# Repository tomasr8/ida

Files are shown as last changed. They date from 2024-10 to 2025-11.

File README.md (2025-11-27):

# Ida - 3-key macropad

<p align="middle">
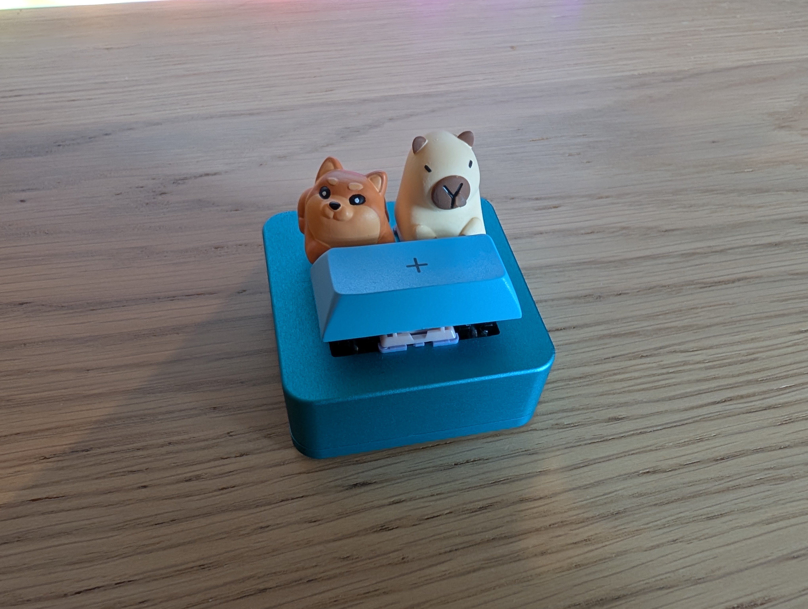
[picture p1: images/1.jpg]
  
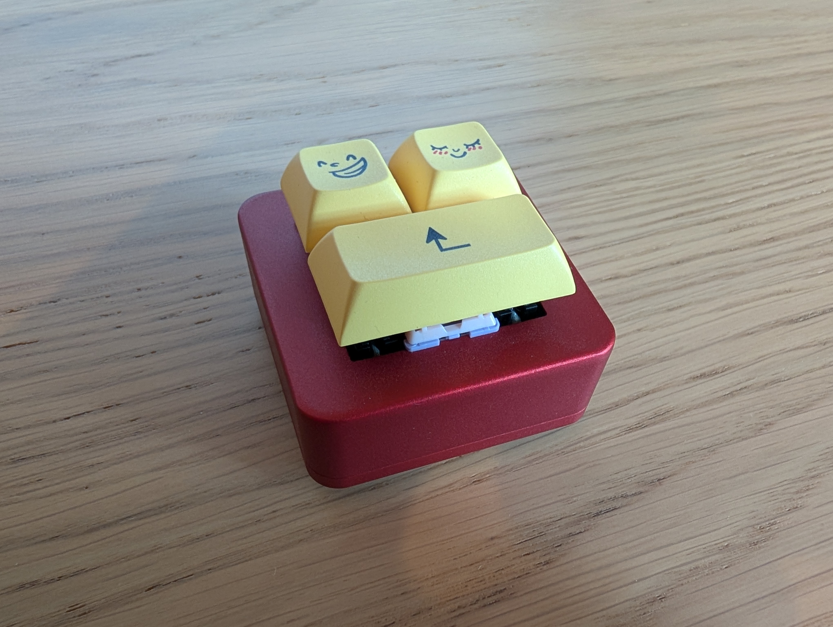
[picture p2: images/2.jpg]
  
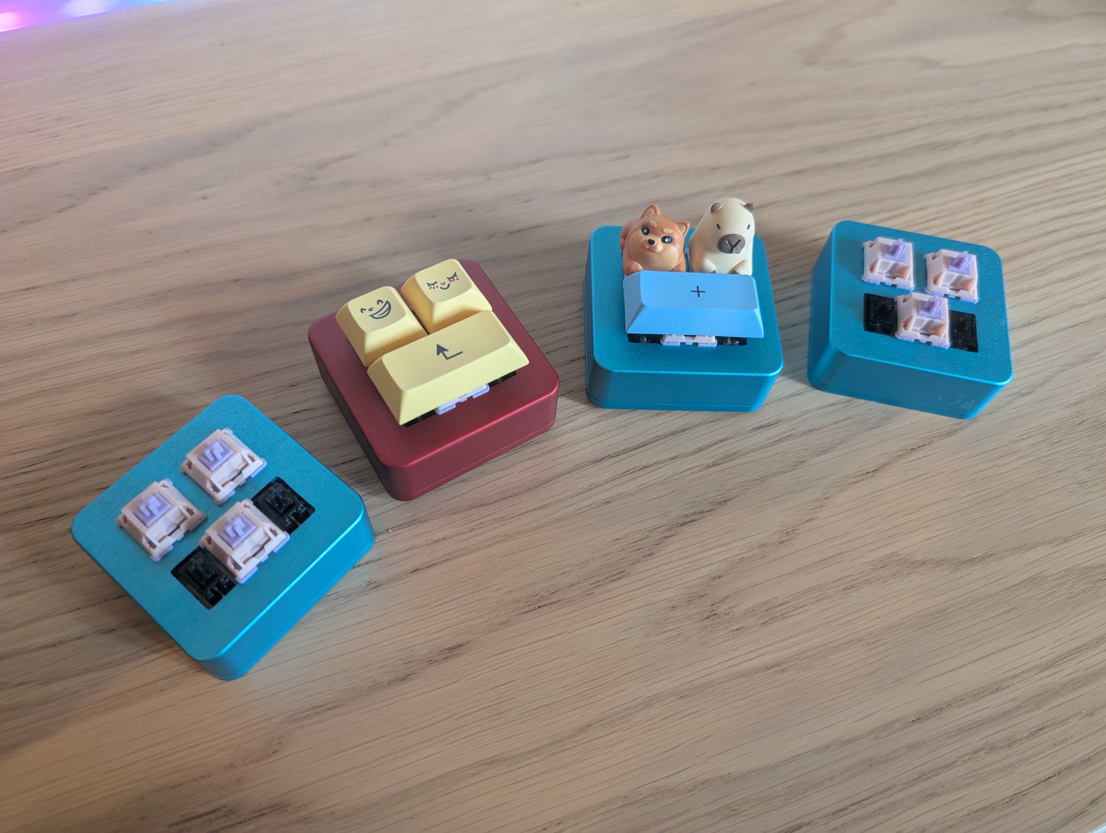
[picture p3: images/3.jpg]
  
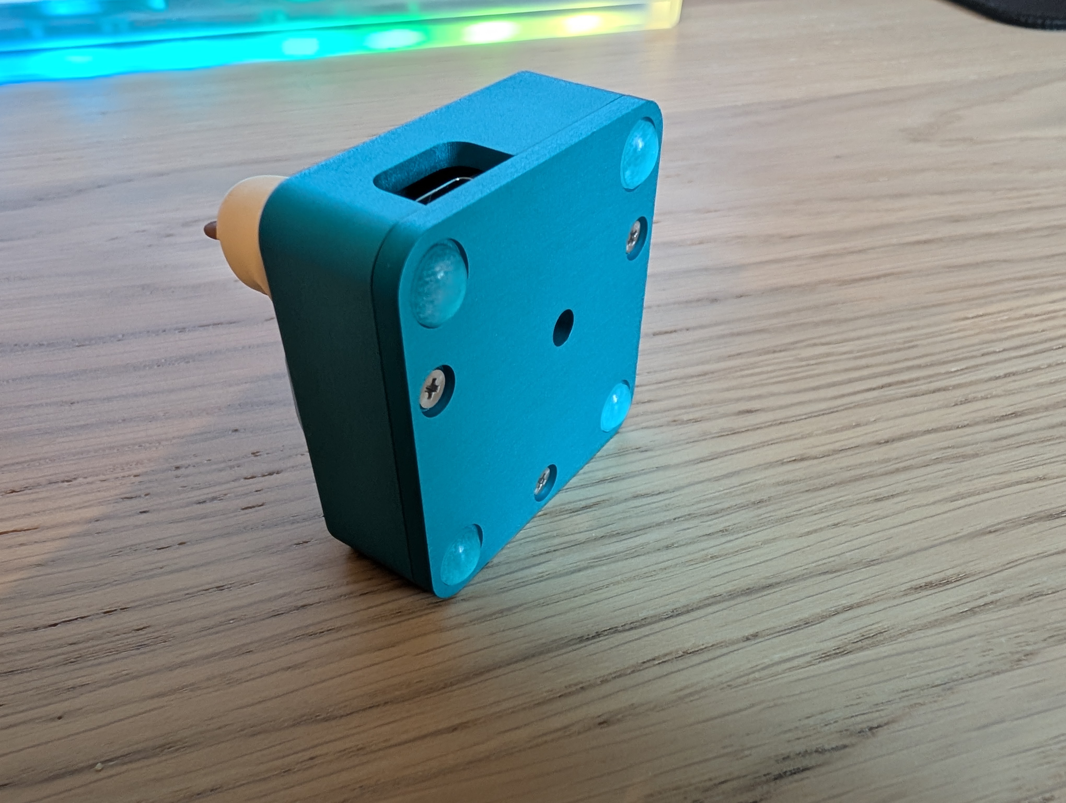
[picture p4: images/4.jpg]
  
</p>

# Table of Contents

- [Bill of Materials](#bill-of-materials)
- [Getting the parts made](#getting-the-parts-made)
- [Build guide](#build-guide)
- [Programming](#programming)
- [Schematics](#schematics)

# Bill of Materials

- **2x** 12x1 pin header
- **1x** Diode (_1N4148 DO-35_)
- **1x** Push button for resetting the board (_4x4x1.5mm_)
- **1x** Pro Micro or something with compatible pinout
- **3x** Keyboard switch
- **1x** 2u stabilizer
- **4x** 8mm rubber feet
- **3x** M2.5 screws
- Steady hands

# Getting the parts made

## PCB 

The gerbers are included in the repo in the [kicad](kicad/) directory. You can simply upload the gerbers to a service like JLCPCB.

Not that the entire Kicad project is included so you can also regenerate the gerbers with different settings if needed or adjust the PCB.

## Case

The case was CNC'd out of aluminium (again by JLCPCB). The case is made up of two ([top](top.stl), [bottom](bottom.stl)) parts.

The two parts are held together using 3 M2.5 screws. There is also a [drawing](drawing.pdf) showing the exact placement of the threads.

It might be possible to 3D print the case, but the screw threads might make it difficult.

# Build guide

**Step 1**: Solder the reset switch and the diode:

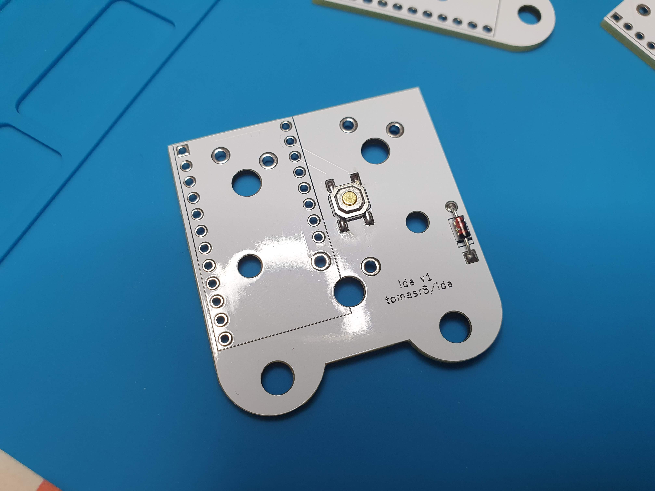
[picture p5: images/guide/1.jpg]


**Step 2**: Solder the pin headers:

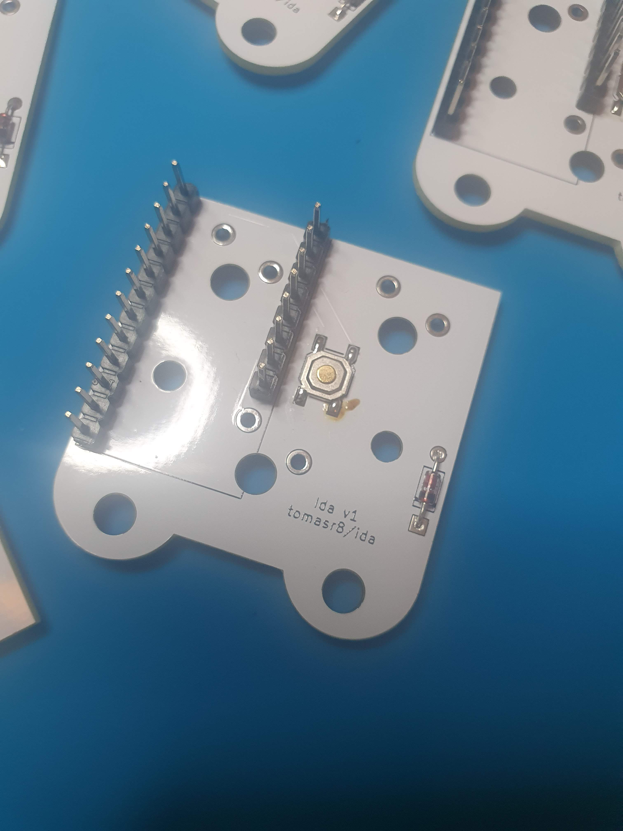
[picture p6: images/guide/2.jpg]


**Step 3**: Place the stabilizers:

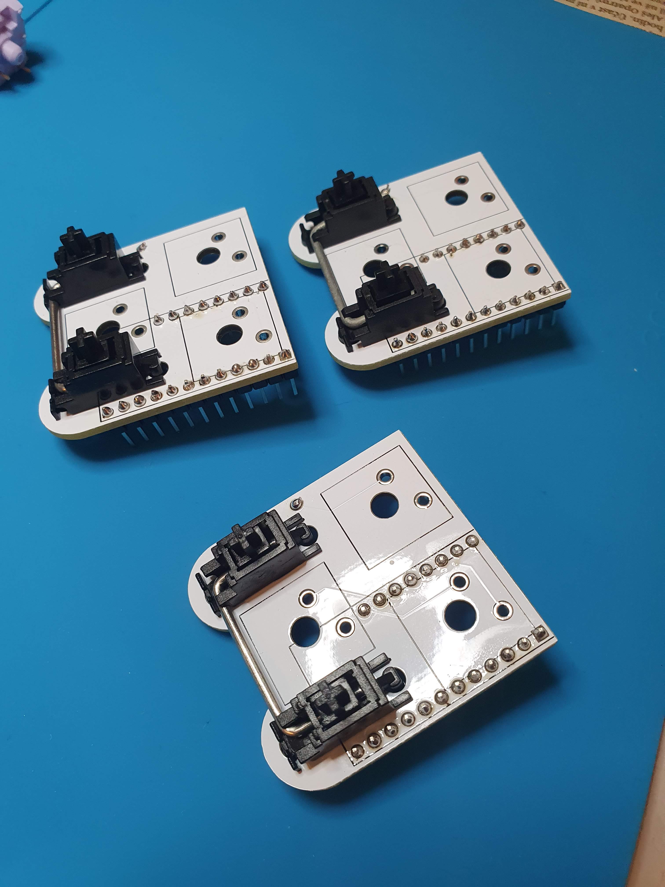
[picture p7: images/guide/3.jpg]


**Step 4**: Place switches in the enclosure:

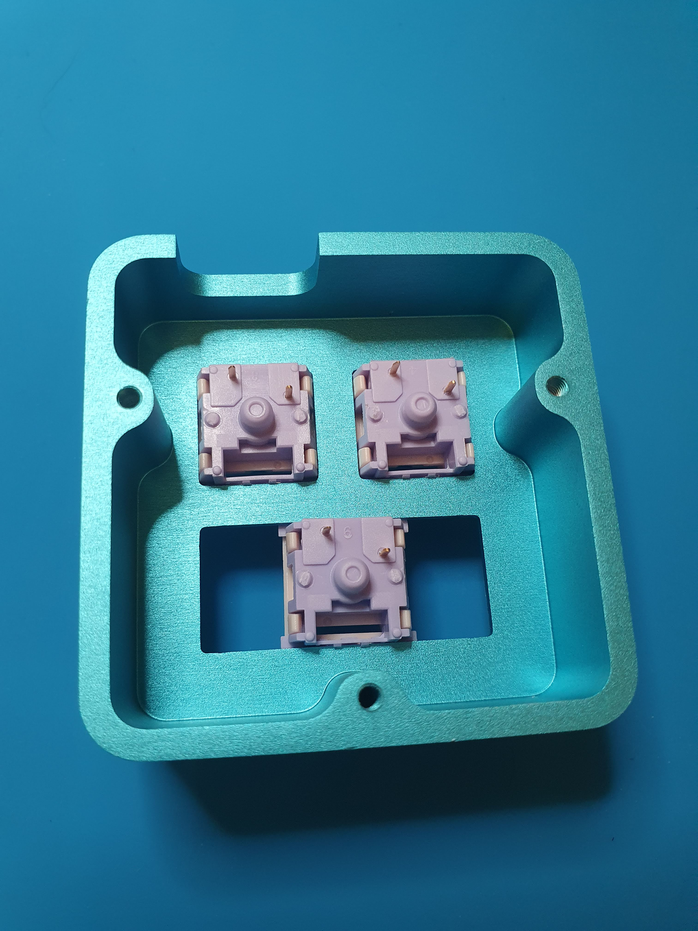
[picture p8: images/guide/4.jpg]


**Step 5**: Place the PCB inside the enclosure and solder the switches:

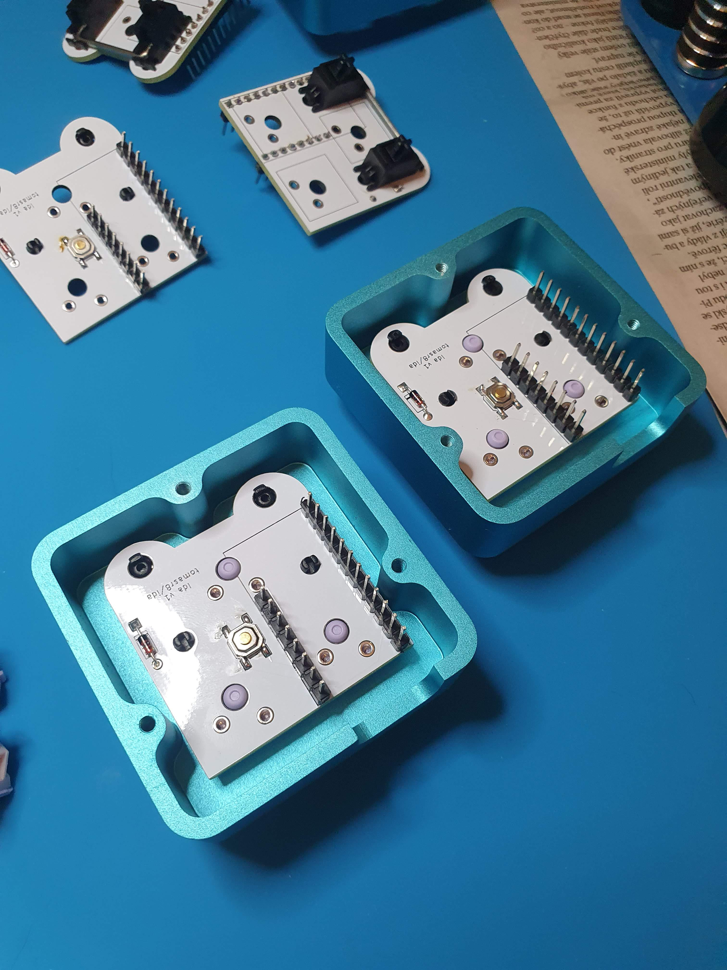
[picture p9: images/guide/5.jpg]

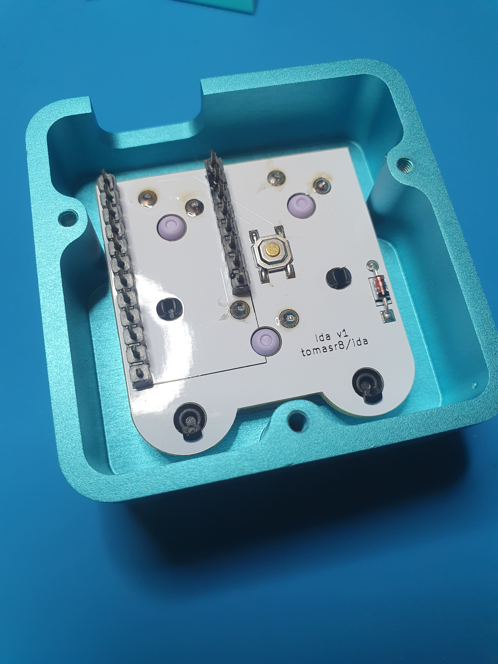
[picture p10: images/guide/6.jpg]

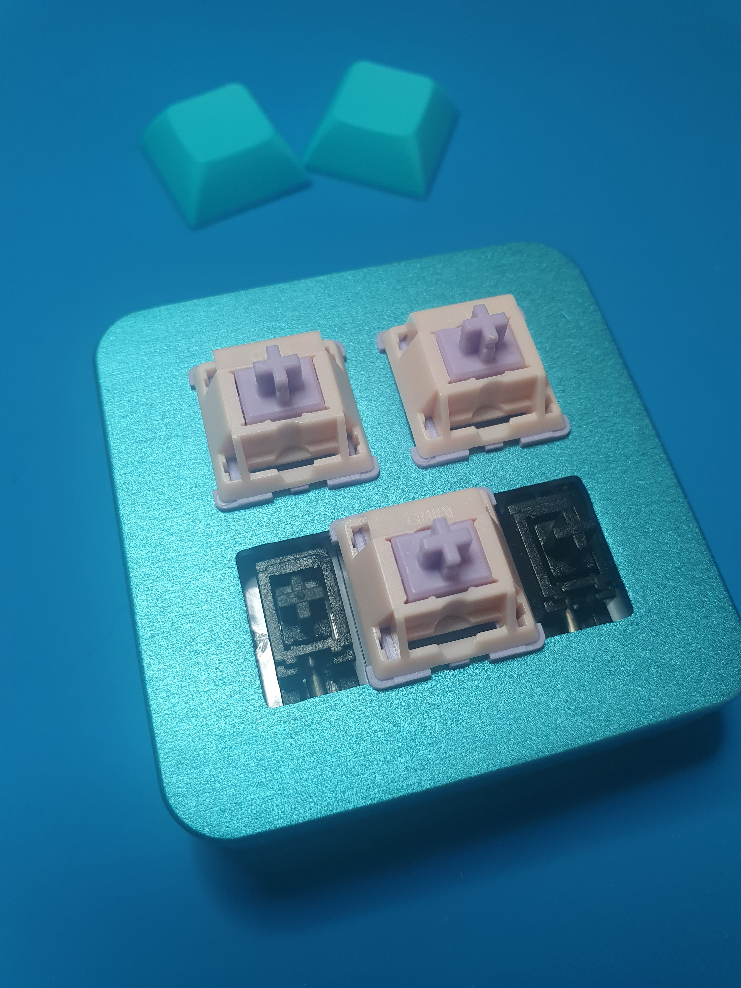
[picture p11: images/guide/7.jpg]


**Step 6**: Place and solder the Pro Micro:

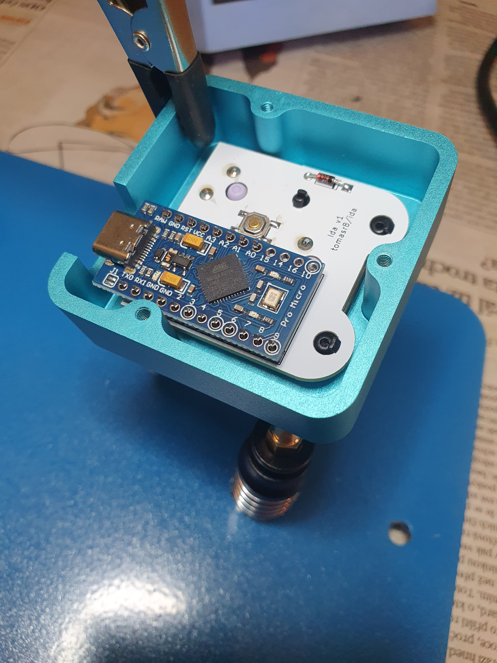
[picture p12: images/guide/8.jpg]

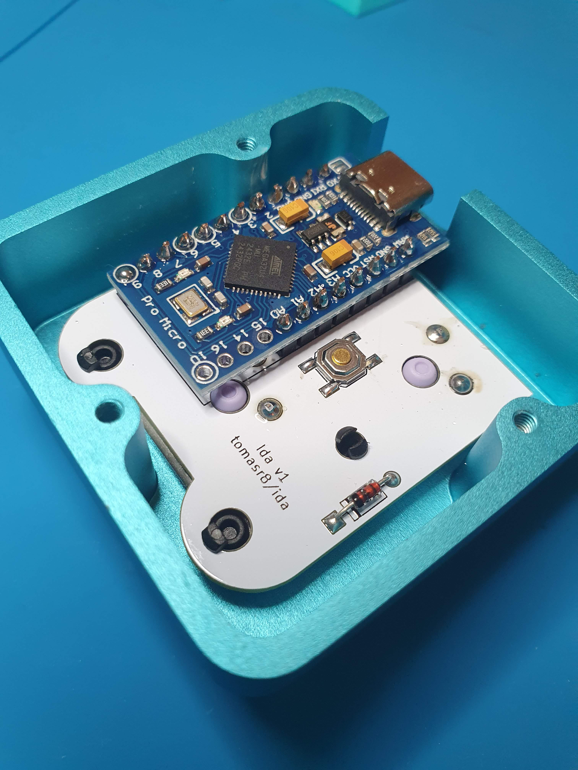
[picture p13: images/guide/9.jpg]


**Step 7**: Screw the bottom part of the case:

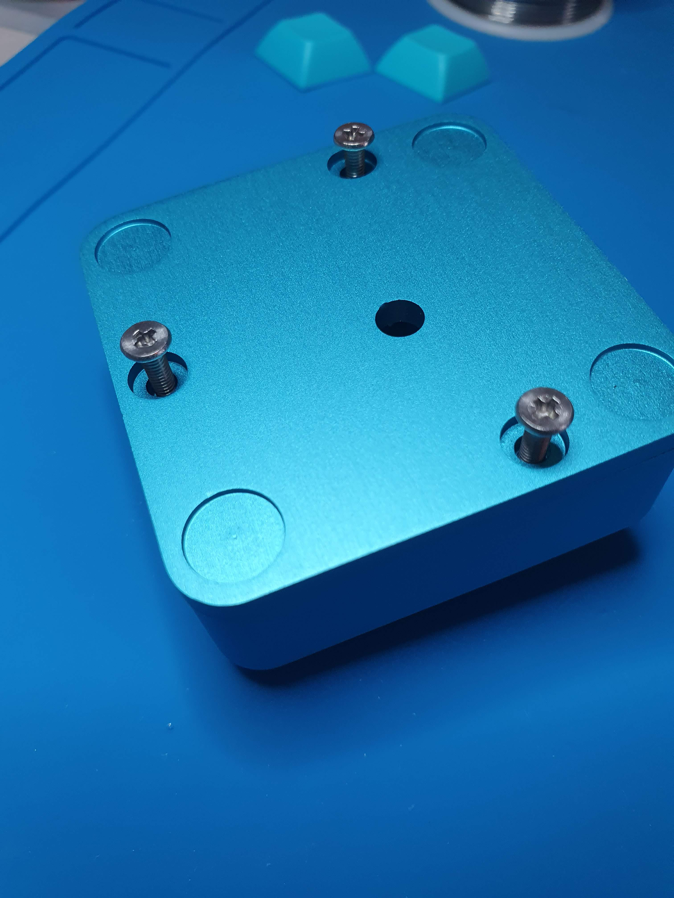
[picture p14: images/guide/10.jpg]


**Done!**



# Programming

I use QMK for programming the macropad. You can use my fork of QMK to change the keymap:
https://github.com/tomasr8/qmk_firmware/tree/ida/keyboards/ida

# Schematics

<p align="middle">
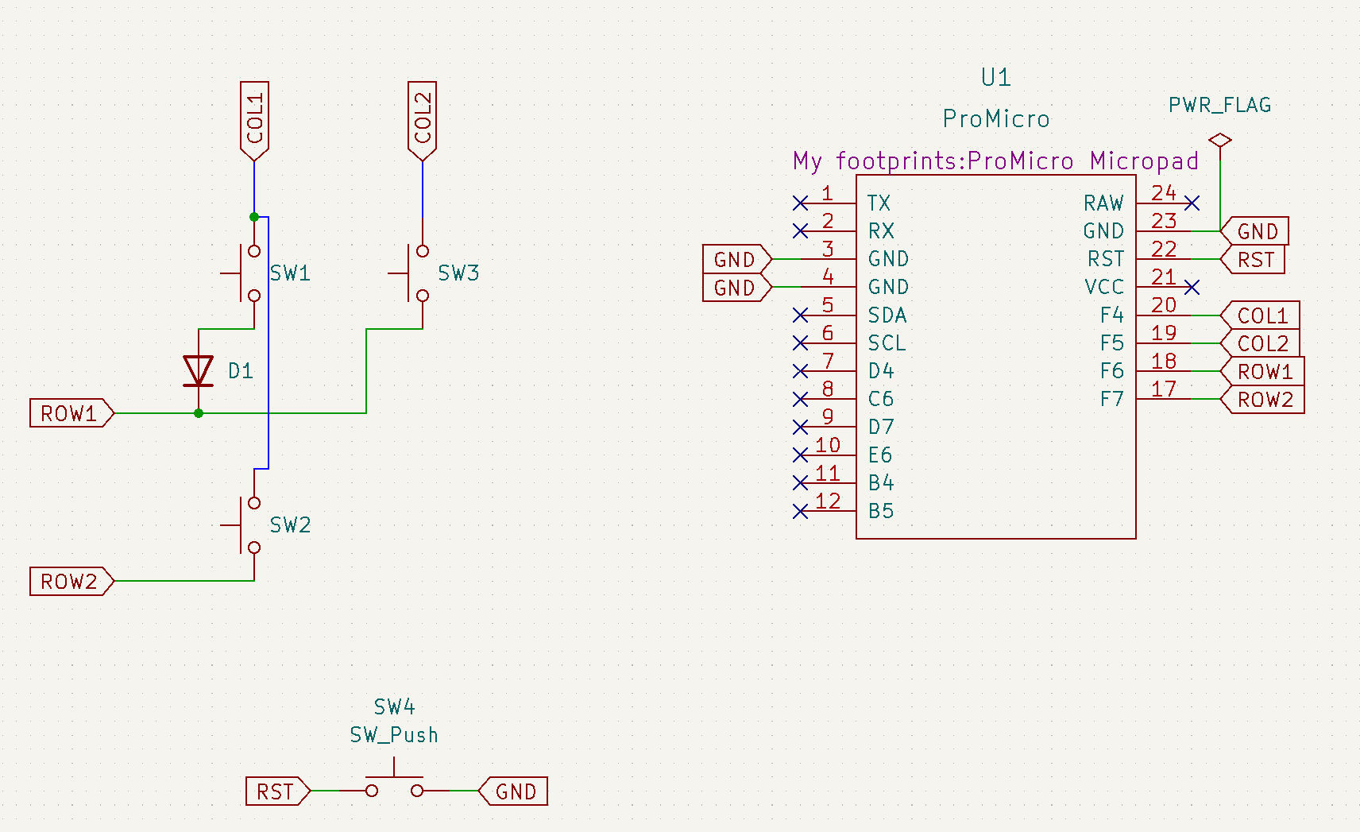
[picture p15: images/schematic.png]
  
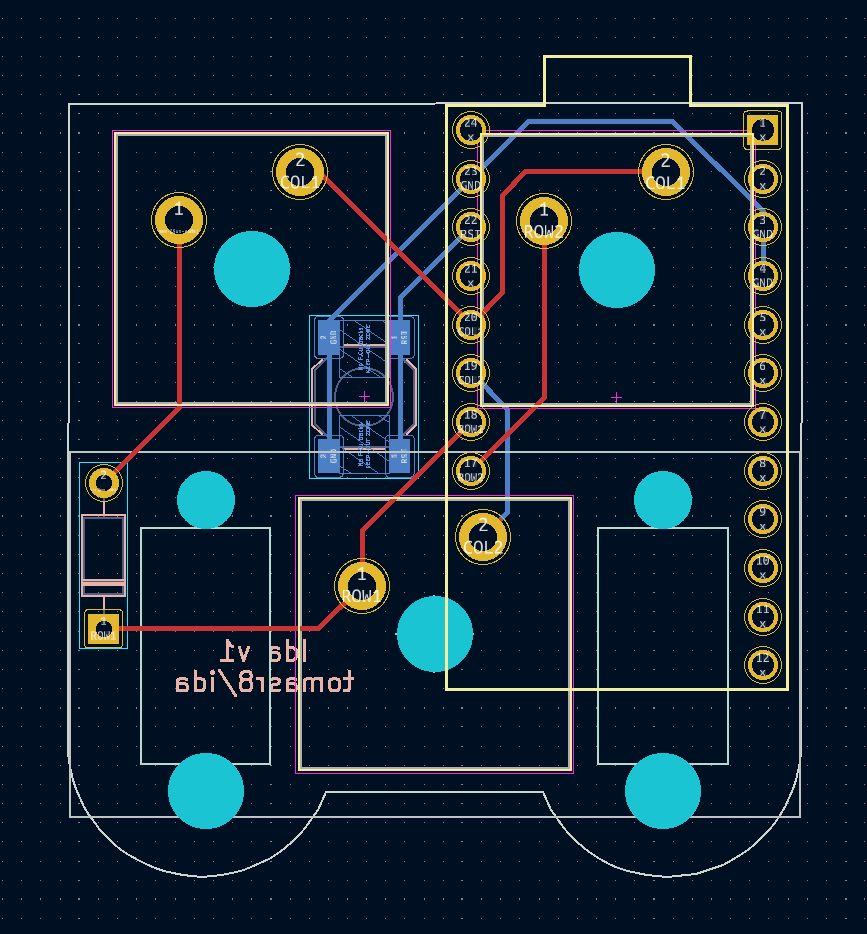
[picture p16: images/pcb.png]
  
</p>

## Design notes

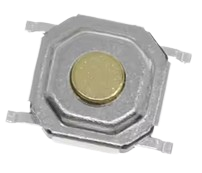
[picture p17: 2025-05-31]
images/pushbtn.png

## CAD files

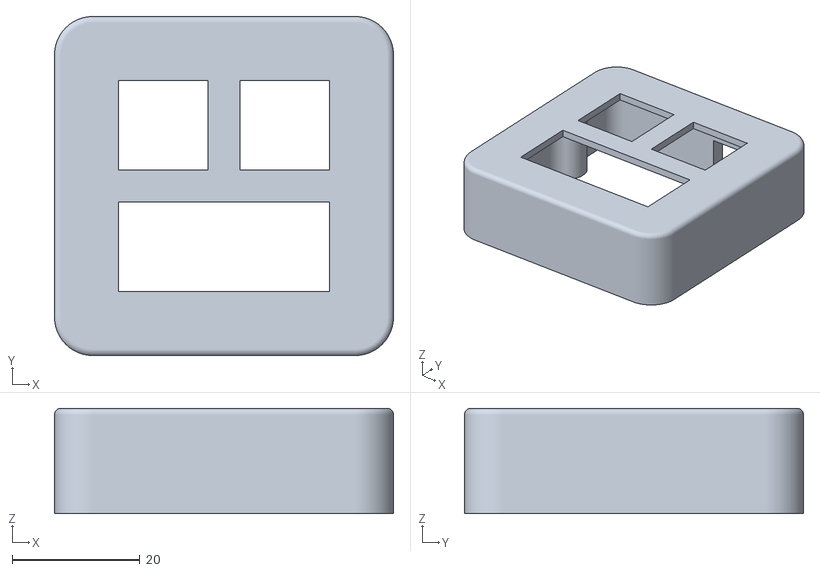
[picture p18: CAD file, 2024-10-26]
top.stl
53.0 x 53.0 x 16.5

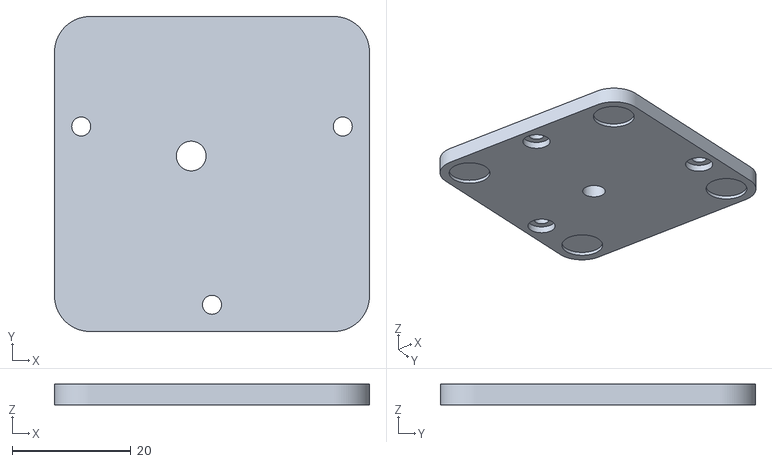
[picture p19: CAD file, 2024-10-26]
bottom.stl
53.0 x 53.0 x 3.50

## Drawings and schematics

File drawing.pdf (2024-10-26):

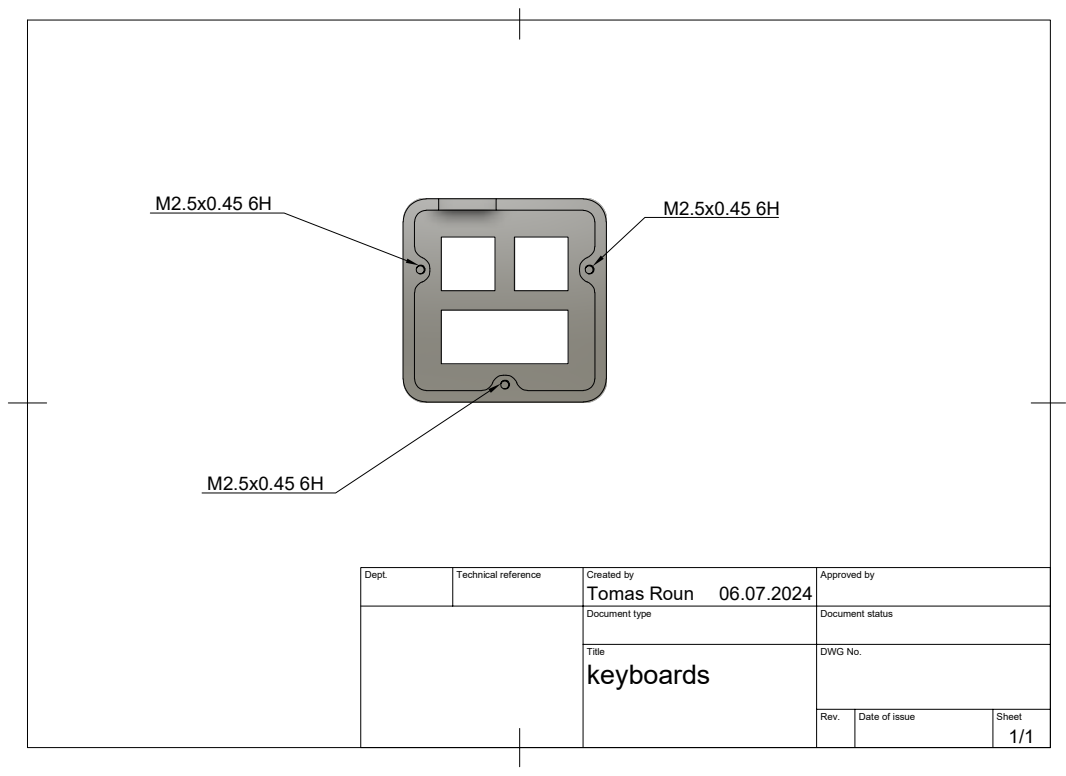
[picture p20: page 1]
Dept.; Technical reference; Created by; Approved by; Document type; Document status; Rev.; Date of issue; Sheet 06.07.2024; Tomas Roun

Title keyboards | DWG No.

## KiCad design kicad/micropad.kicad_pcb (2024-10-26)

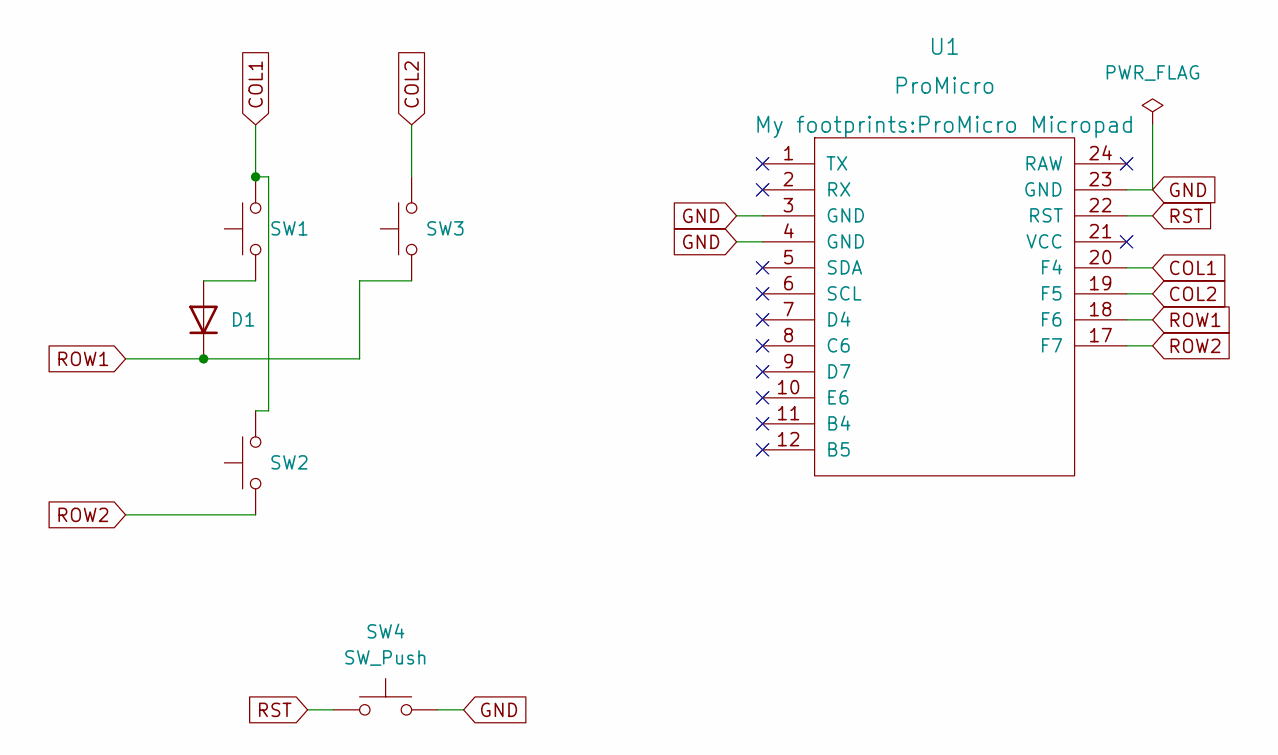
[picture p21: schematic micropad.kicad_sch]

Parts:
D1: 1N4148; D_DO-35_SOD27_P7.62mm_Horizontal
SW1, SW2: SW_Push; SW_Cherry_MX_Plate
SW3: SW_Push; SW_Cherry_MX_Plate_2.00u
SW4: SW_Push; SW_SPST_SKQG_WithoutStem
U1: ProMicro; ProMicro Micropad

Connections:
COL1: SW1.2, SW2.2, U1.20 (F4)
COL2: SW3.2, U1.19 (F5)
GND: SW4.2, U1.3 (GND), U1.4 (GND), U1.23 (GND)
unnamed: D1.2 (A), SW1.1
ROW1: D1.1 (K), SW3.1, U1.18 (F6)
ROW2: SW2.1, U1.17 (F7)
RST: SW4.1, U1.22 (RST)

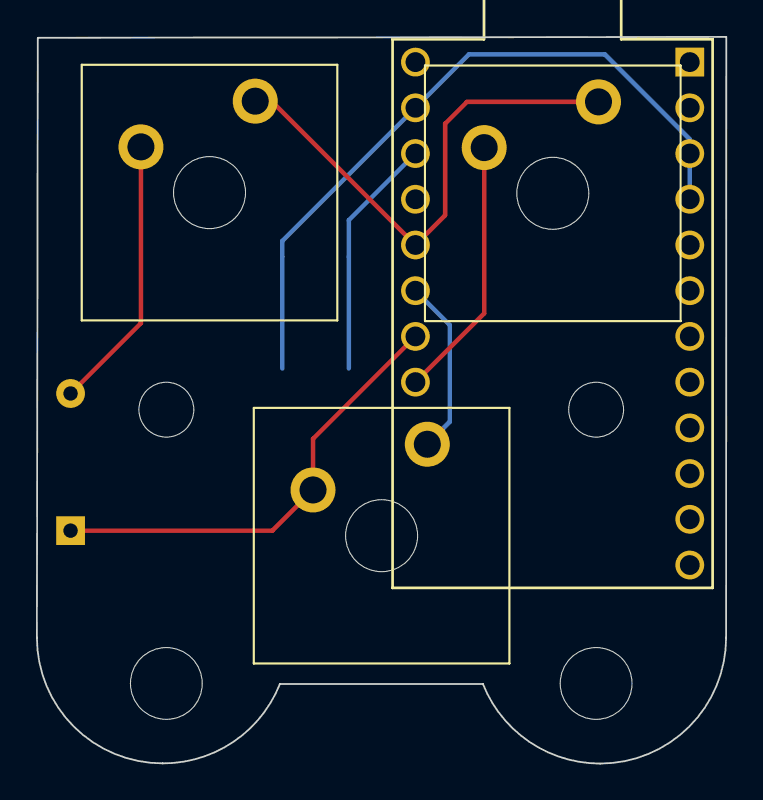
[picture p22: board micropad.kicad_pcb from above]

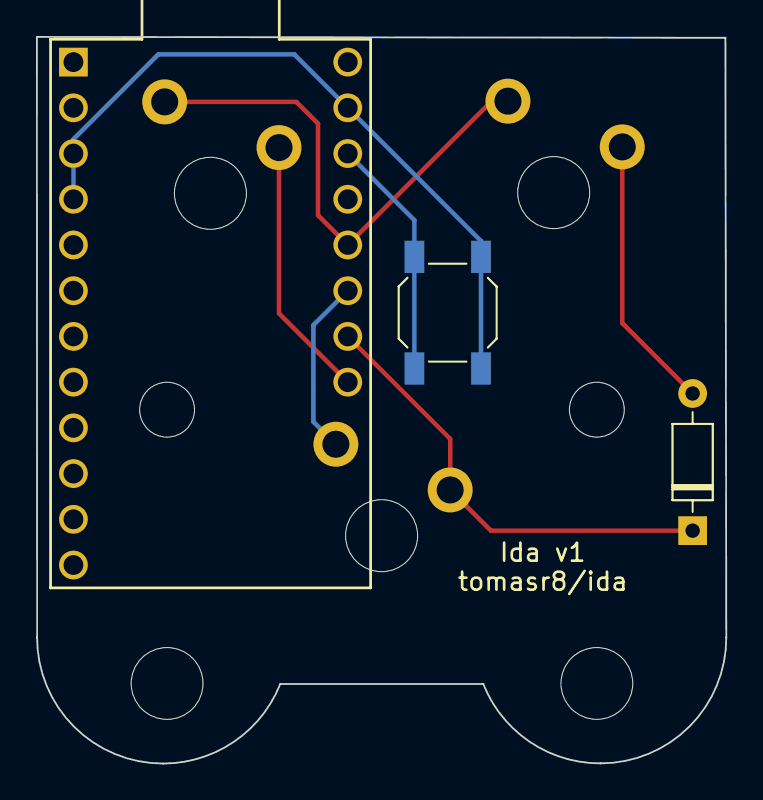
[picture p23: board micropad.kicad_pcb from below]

Board: 2 copper layers, 38.3 x 40.4 mm, 6 parts (3 on the bottom side), 7 nets.
